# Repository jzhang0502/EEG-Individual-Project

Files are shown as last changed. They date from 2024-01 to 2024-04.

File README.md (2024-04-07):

# Electroencephalogram Device with Integrated Signal Processing for Daily Operations
## Author:
Yiyou Zhang



## About The Project 🧠:
This project aims to create an Electroencephalogram (EEG) system that records and utilises the user's neuroactivities, enabling the user to remotely activate a coffee machine with only the thoughts of wanting more coffee. It is advised, however, to consume caffeine in a responsible and moderate quantity.

## Milestones:
- [ ] Complete building functional EEG device
    - [x] Research on fundamental mechanisms of an EEG headset
    - [x] Identify and sketch out primary circuit elements
    - [x] Create schematic of EEG device on LTspice
    - [x] Source all required circuit components on DigiKey
    - [x] Complete project symbol library and overall schematic on KiCad
    - [ ] Complete PCB design on KiCad
    - [ ] Finish assembling all components on custom PCB and test out EEG device
- [ ] Perform signal processing and analysis on EEG data
- [ ] Create models capable of recognising specific EEG activities

## License:

Distributed under the MIT License. See `LICENSE.txt` for more information.

<p align="right">(<a href="#readme-top">back to top</a>)</p>

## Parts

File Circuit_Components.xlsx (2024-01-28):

Section | Part | Value | Seial Number | Quantity | Price | PxQ
Instrumentation amplifier
 | Capacitor | 0.1μF | ECP-U1C104MA5 (https://www.digikey.com.au/en/products/detail/panasonic-electronic-components/ECP-U1C104MA5/285446) | 2 | $1.01 | $2.02 | $39.85
 | Resistor | 2.37kΩ | RN73H1ETTP2371B25 (https://www.digikey.com.au/en/products/detail/koa-speer-electronics-inc/RN73H1ETTP2371B25/9907468) | 1 | $0.56 | $0.56
 | Instrumentation amp |  | INA819ID (https://www.digikey.com.au/en/products/detail/texas-instruments/INA819ID/9858338) | 1 | $10.83 | $10.83
Driven right leg circuit
 | Resistor | 22kΩ | RN73H1JTTD2202D25 (https://www.digikey.com.au/en/products/detail/koa-speer-electronics-inc/RN73H1JTTD2202D25/10684034) | 2 | $0.33 | $0.66
 | Resistor | 10kΩ | RN73H1JTTD1002D25 (https://www.digikey.com.au/en/products/detail/koa-speer-electronics-inc/RN73H1JTTD1002D25/10687052) | 1 | $0.33 | $0.33
 | Resistor | 499kΩ | RN73H1JTTD4993B25 (https://www.digikey.com.au/en/products/detail/koa-speer-electronics-inc/RN73H1JTTD4993B25/10685917) | 1 | $0.52 | $0.52
 | Capacitor | 5.6nF | ECH-U1C562GX5 (https://www.digikey.com.au/en/products/detail/panasonic-electronic-components/ECH-U1C562GX5/353623) | 1 | $0.88 | $0.88
 | Op amp |  | OPA172IDR (https://www.digikey.com.au/en/products/detail/texas-instruments/OPA172IDR/4695363) | 1 | $2.28 | $2.28
Non-inverting op amp
 | Resistor | 100kΩ | RN73H1JTTD1003D25 (https://www.digikey.com.au/en/products/detail/koa-speer-electronics-inc/RN73H1JTTD1003D25/10680166) | 1 | $0.33 | $0.33
 | Resistor | 1.8kΩ | RN73H1JTTD1801B25 (https://www.digikey.com.au/en/products/detail/koa-speer-electronics-inc/RN73H1JTTD1801B25/10682027) | 1 | $0.52 | $0.52
 | Capacitor | 0.033μF | ECH-U1H333JX5 (https://www.digikey.com.au/en/products/detail/panasonic-electronic-components/ECH-U1H333JX5/340777) | 1 | $1.18 | $1.18
 | Op amp |  | OPA172IDR (https://www.digikey.com.au/en/products/detail/texas-instruments/OPA172IDR/4695363) | 1 | $2.28 | $2.28
Inverting op amp
 | Resistor | 100kΩ | RN73H1JTTD1003D25 (https://www.digikey.com.au/en/products/detail/koa-speer-electronics-inc/RN73H1JTTD1003D25/10680166) | 1 | $0.33 | $0.33
 | Resistor | 5.6kΩ | RN73H1JTTD5601B25 (https://www.digikey.com.au/en/products/detail/koa-speer-electronics-inc/RN73H1JTTD5601B25/10686607) | 1 | $0.52 | $0.52
 | Op amp |  | OPA172IDR (https://www.digikey.com.au/en/products/detail/texas-instruments/OPA172IDR/4695363) | 1 | $2.28 | $2.28
Inverting summing amp |  |  |  |  |  | $0.00
 | Resistor | 2.37kΩ | RN73H1ETTP2371B25 (https://www.digikey.com.au/en/products/detail/koa-speer-electronics-inc/RN73H1ETTP2371B25/9907468) | 3 | $0.56 | $1.68
 | Resistor | 10kΩ | RN73H1JTTD1002D25 (https://www.digikey.com.au/en/products/detail/koa-speer-electronics-inc/RN73H1JTTD1002D25/10687052) | 1 | $0.33 | $0.33
 | Resistor | 4.99kΩ | RN73H1JTTD4991B25 (https://www.digikey.com.au/en/products/detail/koa-speer-electronics-inc/RN73H1JTTD4991B25/10678570) | 1 | $0.52 | $0.52
 | Op amp |  | OPA172IDR (https://www.digikey.com.au/en/products/detail/texas-instruments/OPA172IDR/4695363) | 1 | $2.28 | $2.28
Inverting op amp
 | Resistor | 10kΩ | RN73H1JTTD1002D25 (https://www.digikey.com.au/en/products/detail/koa-speer-electronics-inc/RN73H1JTTD1002D25/10687052) | 2 | $0.33 | $0.66
 | Op amp |  | OPA172IDR (https://www.digikey.com.au/en/products/detail/texas-instruments/OPA172IDR/4695363) | 1 | $2.28 | $2.28
RFI filter
 | Capacitor | 5.6nF | ECH-U1C562GX5 (https://www.digikey.com.au/en/products/detail/panasonic-electronic-components/ECH-U1C562GX5/353623) | 2 | $0.88 | $1.76
 | Capacitor | 0.033μF | ECH-U1H333JX5 (https://www.digikey.com.au/en/products/detail/panasonic-electronic-components/ECH-U1H333JX5/340777) | 1 | $1.18 | $1.18
 | Resistor | 4.99kΩ | RN73H1JTTD4991B25 (https://www.digikey.com.au/en/products/detail/koa-speer-electronics-inc/RN73H1JTTD4991B25/10678570) | 2 | $0.52 | $1.04
ESD Protection
 | Diode |  | D5V0F1U2S9-7 (https://www.digikey.com.au/en/products/detail/diodes-incorporated/D5V0F1U2S9-7/4967035) | 4 | $0.65 | $2.60

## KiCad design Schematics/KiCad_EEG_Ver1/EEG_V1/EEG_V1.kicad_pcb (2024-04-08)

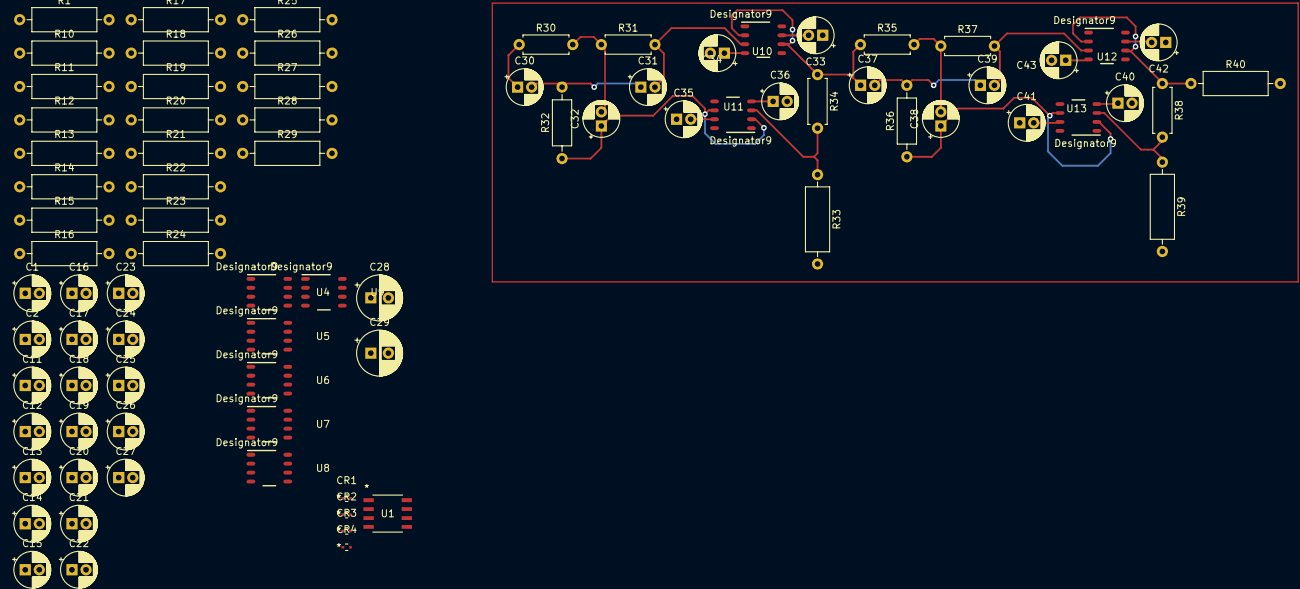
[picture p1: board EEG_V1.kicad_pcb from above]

Board: 2 copper layers, 82 parts (0 on the bottom side), 35 nets.

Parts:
C1, C2, C14, C15, C16, C17, C19, C20, C22, C23, C24, C25, C26, C27, C30, C31, C33, C34, C35, C36, C37, C39, C40, C41, C42, C43: 0.1u; CP_Radial_D5.0mm_P2.00mm
C11, C21: 33n; CP_Radial_D5.0mm_P2.00mm
C12, C13, C18: 5.6n; CP_Radial_D5.0mm_P2.00mm
C28, C29: 10u; CP_Radial_D6.3mm_P2.50mm
C32, C38: 0.2u; CP_Radial_D5.0mm_P2.00mm
CR1, CR2, CR3, CR4: D5V0F1U2S9-7; CR_0F1U2S9-7_DIO
R1: 2k; R_Axial_DIN0309_L9.0mm_D3.2mm_P12.70mm_Horizontal
R10, R11, R26: 4.99k; R_Axial_DIN0309_L9.0mm_D3.2mm_P12.70mm_Horizontal
R12, R13: 22k; R_Axial_DIN0309_L9.0mm_D3.2mm_P12.70mm_Horizontal
R14, R15, R16, R18, R25, R28, R33, R39, R40: 10k; R_Axial_DIN0309_L9.0mm_D3.2mm_P12.70mm_Horizontal
R17: 499k; R_Axial_DIN0309_L9.0mm_D3.2mm_P12.70mm_Horizontal
R19, R22: 100k; R_Axial_DIN0309_L9.0mm_D3.2mm_P12.70mm_Horizontal
R20: 1.8k; R_Axial_DIN0309_L9.0mm_D3.2mm_P12.70mm_Horizontal
R21: 5.6k; R_Axial_DIN0309_L9.0mm_D3.2mm_P12.70mm_Horizontal
R23, R24, R27: 2.37k; R_Axial_DIN0309_L9.0mm_D3.2mm_P12.70mm_Horizontal
R29: R; R_Axial_DIN0309_L9.0mm_D3.2mm_P12.70mm_Horizontal
R30, R31, R35, R37: 32k; R_Axial_DIN0207_L6.3mm_D2.5mm_P7.62mm_Horizontal
R32, R36: 16k; R_Axial_DIN0207_L6.3mm_D2.5mm_P10.16mm_Horizontal
R34, R38: 250; R_Axial_DIN0207_L6.3mm_D2.5mm_P7.62mm_Horizontal
U1: INA819IDGK; INA819ID
U4, U5, U6, U7, U8, U9, U10, U11, U12, U13: OPA172IDR

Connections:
/Vout1: C21.1, R19.1, R20.2, U1.7, U6.3 (IN+)
DRL_in: R12.1, R13.1, U5.3 (IN+)
EEG_out: R28.2, U9.6 (OUT)
Inv_Summing_Amp_in: R23.2, R24.1, R27.1, U8.2 (IN-)
unnamed: C11.1, C12.1, CR2.2, CR4.1, R10.2, R15.1
unnamed: C11.2, C13.2, CR1.2, CR3.1, R11.2, R16.1
unnamed: C30.2, C31.1, R32.2
unnamed: C32.2, R30.2, R31.1
unnamed: C37.2, C39.1, R36.2
unnamed: C38.2, R35.2, R37.1
unnamed: R1.1, R12.2, U1.2 (Rg)
unnamed: R1.2, R13.2, U1.3 (Rg)
unnamed: R24.2, R25.2, R26.2
unnamed: R15.2, U1.4 (+)
unnamed: R16.2, U1.1 (-)
unnamed: C18.1, R14.2, R17.1, U4.2 (IN-)
unnamed: C18.2, R17.2, R18.1, U4.6 (OUT)
unnamed: R14.1, U5.2 (IN-), U5.6 (OUT)
unnamed: C21.2, R19.2, R21.1, U6.6 (OUT)
unnamed: R21.2, R22.1, U7.2 (IN-)
unnamed: R22.2, R23.1, U7.6 (OUT)
unnamed: R27.2, R29.1, U8.6 (OUT)
unnamed: R28.1, R29.2, U9.2 (IN-)
unnamed: C31.2, R31.2, U10.3 (IN+)
unnamed: C37.1, R34.1, R35.1, U10.2 (IN-), U10.6 (OUT)
unnamed: R33.1, R34.2, U11.3 (IN+)
unnamed: C32.1, R32.1, U11.2 (IN-), U11.6 (OUT)
unnamed: C39.2, R37.2, U12.3 (IN+)
unnamed: R38.1, R40.1, U12.2 (IN-), U12.6 (OUT)
unnamed: R38.2, R39.1, U13.3 (IN+)
unnamed: C38.1, R36.1, U13.2 (IN-), U13.6 (OUT)
Notch_in: C30.1, R30.1
Notch_out: C1.1, C2.2, C12.2, C13.1, C14.1, C15.2, C16.1, C17.2, C19.1, C20.2, C22.1, C23.2, C24.1, C25.2, C26.2, C27.1, C28.2, C29.1, C33.1, C34.2, C35.1, C36.2, C40.2, C41.1, C42.1, C43.2, R20.1, R25.1, R33.2, R39.2, R40.2, U1.6 (Ref), U4.3 (IN+), U7.3 (IN+), U8.3 (IN+), U9.3 (IN+)
V++: C1.2, C14.2, C16.2, C19.2, C22.2, C24.2, C27.2, C29.2, C33.2, C35.2, C41.2, C42.2, CR1.1, CR2.1, R26.1, U1.8 (V+), U4.7 (V+), U5.7 (V+), U6.7 (V+), U7.7 (V+), U8.7 (V+), U9.7 (V+), U10.7 (V+), U11.7 (V+), U12.7 (V+), U13.7 (V+)
V--: C2.1, C15.1, C17.1, C20.1, C23.1, C25.1, C26.1, C28.1, C34.1, C36.1, C40.1, C43.1, CR3.2, CR4.2, U1.5 (V-), U4.4 (V-), U5.4 (V-), U6.4 (V-), U7.4 (V-), U8.4 (V-), U9.4 (V-), U10.4 (V-), U11.4 (V-), U12.4 (V-), U13.4 (V-)

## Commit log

2024-01-02 Updated main README.txt milestone progress
    Completed researching, and sketching first overall circuit schematic on LTspice
2024-01-02 Initial sketch of EEG device gain stages
    The sketch includes the following:
    - 2x9V battery power source
    - INA819 inst amp with 21 gain
    - Non-inv op amp with 55.95 gain
    - Non-inv op amp with 18.86 gain
    - Total gain 22156
2024-01-02 Updated EEG_Schematic_LT
    Following additions:
    - Driven right leg circuit with gain 50
    - Added capacitor on stage 2 non-inv op amp as low-pass filter with Fc = 48Hz
    - Additional descriptions on circuit blocks
2024-01-02 Updated EEG_Schematic_LT.asc
    Following additions and alterations:
    - Added voltage source as "Electrode" that simulates electrode readings
    - Connected all parts of EEG circuit
    - Added optional high-pass filter to connect to inst amp
    - Changed inst amp gain to 22.10
    - Changed stage 2 non-inv op amp gain to 56.56
    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
2024-01-02 Updated EEG_Schematic_LT.asc
    Following changes:
    - Changed stage 3 non-inv op amp gain to 17.86
    - Total gain is now 22322.82
2024-01-02 Updated EEG_Schematic_LT.asc
    - Additional documentation to explain every circuit element
    - Stage 1 INA819 inst amp gain is 22.10
    - Stage 2 non-inv op amp gain is 56.56
    - Stage 3 inv op amp gain is -17.86
    - Stage 4 inv summing amp gain is -1 with offset 2.4969V
    - Stage 5 inv op amp gain is -1
    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
2024-01-05 Updated EEG_Schematic_LT.asc
    Added the following/
    - RFI filter with Fc = 445.4578Hz
    - ESD protection circuit with 4 diodes
2024-01-06 Uploaded KiCad Symbol Library
    Library includes imported symbols from DigiKey for corresponding circuit parts.
2024-01-06 Uploaded KiCad project files
    All created files for KiCad project, including schematics, pcb etc.
    [EEG_Design.kicad_pcb, EEG_Design.kicad_sch]
2024-01-06 Created Excel spreadsheet for circuit component listing
    Lists the following for every circuit component needed to order/
    - Value
    - Serial number
    - Quantity
    - Price
    [Circuit_Components.xlsx]
2024-01-08 Updated circuit_components spreadsheet
    Added newly selected op amp
    [Circuit_Components.xlsx]
2024-01-09 Updated spreadsheet & schematic
    - Added chosen diode and op amp for components spreadsheet
    - Created schematic file in KiCad
    - Updated KiCad component library with added diode and op amp
    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
    [Circuit_Components.xlsx, EEG_Design.kicad_sch]
2024-01-28 Updated KiCad project schematic & symbol library
    Changed diode choice to D5V0F1U2S9-7
    Total cost currently $39.85
    [Circuit_Components.xlsx]
2024-03-18 KiCad schematic mostly done
    [EEG_V1.kicad_pcb, EEG_V1.kicad_sch]
2024-03-19 Added notch filter 50Hz
    [EEG_V1.kicad_sch]
2024-03-22 Schematic update
    [EEG_V1.kicad_sch, untitled.kicad_sch]
2024-04-07 Footprint update
    [EEG_V1.kicad_pcb, Sub_Components.kicad_sch]
2024-04-08 Twin rejection filter modeled
    This is a prelim layout but i definitely reckon i can squeeze the rectangular config of the two stages into more of a square config.
    [EEG_V1.kicad_pcb]

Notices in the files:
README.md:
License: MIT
